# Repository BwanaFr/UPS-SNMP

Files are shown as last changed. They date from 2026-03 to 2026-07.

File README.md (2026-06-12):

# USB UPS to SNMP

## Introduction

This small device is attended to publish USB UPS (tested on some APC models) values to SNMP (v2c).

## Building

### Hardware
Hardware design files (PCB and 3D enclosure) is stored in the `hardware` folder.

### Firmware
The ESP32S3 firmware is built with PlatformIO.
Releases of the firmware are available on my GitHub page.

#### Configuration names
Some configurations are supported.

## Usage
Connect an USB cable in the USB A connector, a PoE enabled RJ45 ethernet connection.
The device is starting using a default IP of 10.10.11.200.
Please navigate to http://10.10.11.200 to change settings (your PC needs to be on the same network).

### Reset to default using buttons procedure
You can do a "on site" reset using the navigation button. To do so, please use this procedure.

1. Connect ethernet cable
2. You have one second to push the button
3. The LED will go white
4. Relase the button
5. Within 200ms, press again the buton
6. Device will start with default configuration

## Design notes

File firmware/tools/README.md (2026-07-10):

UPS-SNMP tools suite
---

# Description

Small Python scripts to performs "automated" actions on UPS-SNMP devices.
The main usage is to batch flash a new firmware version.

# Installation

Install a recent version of Python (>3.6)

Create a new Python venv
``` bash
> python -m venv /path/to/new/virtual/environment
```

Activate it:

Linux:
```bash
> source /path/to/new/virtual/environment/bin/activate
```

Windows (Powershell):
```powershell
> /path/to/new/virtual/environment\Scripts\Activate.ps1
```

Install dependencies (from this folder):
``` bash
> pip install -e .
```

# Usage
``` bash
> python -m ups-snmp-tools
usage: ups-snmp tool [-h] [--timeout TIMEOUT] [--ipColumn IPCOLUMN] [--nameColumn NAMECOLUMN]
                     [--nameSubstitution NAMESUBSTITUTION] [--sheetName SHEETNAME] [--fixName]
                     list update
```

Two parameters are mandatory:
- list: Specify the Excel file listing devices IP and (optional) name
- update: Specify the path to the firmware update file (.fw)

Other parameters:
- timeout: Specify the HTTP timeout (seconds) to give up, default is 5s
- ipColumn: Specify the column in the Excel file containing the device IP address (starting from 1, defaut 2)
- nameColumn: Specify the column in the Excel file containing the device name (starting from 1). This parameter is optional.
- nameSubstitution: Specify a substitution to apply to device name syntax is `SEARCH/REPLACE` where SEARCH is the searched sequence and REPLACE is the replaced sequence.
- sheetName: Name of the Excel sheet to find data in the file.
- fixName: If set, the application will update the device name according to provided name and substitution.

Example:
```bash
python -m ups-snmp-tools devices.xlsx --update waveshare_esp32_eth_ch1115_v0.0.5.fw --nameColumn 1 --nameSubstitution "sw-/ups-" --ipSubstitution "10.10.10/10.10.11" --nameFilter "(?!.*core.*)(sw-.*)"
```

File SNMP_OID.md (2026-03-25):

# OID documentation

The OID documentaion is available directly on the device by browsing http://<device_IP>/oid.html

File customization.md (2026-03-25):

# Device customization

You can apply some device customization to fit your needs / company.
All customizations are made in a `Customization.hpp` file.
If this file exists, the compiler will include it and use customized features. If not, the default behaviour will be used.

## Customizing logo

You can set a custom logo by defining `CUSTOM_LOGO`.
Three variables needs to be set to provide logo data:
```cpp
const int16_t custom_logo_height = 34;              //Logo height in pixels
const int16_t custom_logo_width = 90;               //Logo width in pixels
const unsigned char custom_logo [] PROGMEM = ...    //Byte array containing logo data
```
The logo byte array can be created using [image2cpp](https://javl.github.io/image2cpp/).

## Enabling and customizing auto-configuration

The device can be configured using the button and the OLED display.
To ease the configuration using this UI, the user can set an IP suffix (a digit from 0 to 255) and the device will configure all the required parameters.
This feature is implemented by defining `HAS_AUTOCONFIG` and implementing a `AutoConfig` class.
The `AutoConfig` class have only one static function `static void applyAutoconfig(uint8_t suffix)`.
This function will be called when the user validate the auto-configuration suffix setting.

Implementation of this function is left free.

## Adding OID aliases

If you want to add some aliases to SNMP OID, you can define them in the `Customization.hpp` file.
To do so, define a `OID_ALIAS` and fill a `static const char* oidAlias[][2]` array.
The first column contains the alias value, the second contains the aliased one.
This array should end with two `nullptr` values to detect the end of it.

Adding an alias will not add it in the SNMP get-next request, and will be invisible with `snmp-walk` tool.

## Example `Customization.hpp` file

Here is an example of how you can customize the device.

```cpp
#ifndef _CUSTOMIZATION_HPP__
#define _CUSTOMIZATION_HPP__

#include <Arduino.h>
#include <Configuration.hpp>

/**
 * This file is used for customization of the device such as logo, product name...
 */

//Sets CUSTOM_LOGO to enable custom logo
#define CUSTOM_LOGO 1

//Custom logo height and width
const int16_t custom_logo_height = 34;
const int16_t custom_logo_width = 90;
//Custom logo bitmap (same as default in this example)
const unsigned char custom_logo [] PROGMEM = {
	0x00, 0x00, 0x00, 0x00, 0x00, 0x00, 0x00, 0x00, 0x00, 0x00, 0x00, 0x00, 0x00, 0x00, 0x00, 0x00, 
	0x00, 0x00, 0x00, 0x00, 0x00, 0x00, 0x00, 0x00, 0x00, 0x00, 0x00, 0x00, 0x00, 0x00, 0x00, 0x00, 
	0x00, 0x00, 0x00, 0x00, 0x00, 0x00, 0x00, 0x00, 0x00, 0x00, 0x00, 0x00, 0x00, 0x00, 0x00, 0x00, 
	0x00, 0x00, 0x00, 0x00, 0x00, 0x00, 0x00, 0x00, 0x00, 0x00, 0x00, 0x00, 0x00, 0x00, 0x00, 0x00, 
	0x00, 0x00, 0x00, 0x00, 0x00, 0x00, 0x00, 0x00, 0x00, 0x00, 0x00, 0x00, 0x00, 0x00, 0x84, 0xf0, 
	0xf0, 0x00, 0x00, 0x00, 0x01, 0xe0, 0x07, 0x00, 0x00, 0x00, 0x84, 0x89, 0x88, 0x00, 0x00, 0x00, 
	0x01, 0xe0, 0x0f, 0x00, 0x00, 0x00, 0x84, 0x89, 0x00, 0x00, 0x00, 0x00, 0x07, 0xff, 0xff, 0xe0, 
	0x00, 0x00, 0x84, 0x88, 0xe0, 0x00, 0x00, 0x00, 0x07, 0xff, 0xff, 0xe0, 0x00, 0x00, 0x84, 0xf0, 
	0x38, 0x00, 0x00, 0x00, 0x00, 0x00, 0x00, 0x00, 0x00, 0x00, 0x84, 0x80, 0x08, 0x00, 0x00, 0x00, 
	0x07, 0xff, 0xff, 0xe0, 0x00, 0x00, 0x44, 0x81, 0x08, 0x00, 0x00, 0x00, 0x07, 0x3f, 0xff, 0xe0, 
	0x00, 0x00, 0x78, 0x80, 0xf0, 0x00, 0x00, 0x00, 0x07, 0x3f, 0xff, 0xe0, 0x00, 0x00, 0x00, 0x00, 
	0x00, 0x00, 0x00, 0x00, 0x04, 0x0f, 0xe0, 0x60, 0x00, 0x00, 0x00, 0x00, 0x00, 0x00, 0x00, 0x00, 
	0x06, 0x0f, 0xf0, 0x60, 0x00, 0x00, 0x00, 0x00, 0x00, 0x00, 0x00, 0x00, 0x07, 0x3f, 0xff, 0xe0, 
	0x00, 0x00, 0x00, 0x00, 0x00, 0x00, 0x00, 0x00, 0x07, 0xbf, 0xff, 0xe0, 0x00, 0x00, 0x00, 0x00, 
	0x00, 0x00, 0x00, 0x00, 0x07, 0xff, 0xff, 0xe0, 0x00, 0x00, 0x00, 0x00, 0x00, 0x00, 0x00, 0x00, 
	0x07, 0xff, 0xff, 0xe0, 0x00, 0x00, 0x00, 0x00, 0x00, 0x00, 0x00, 0x00, 0x07, 0xff, 0xff, 0xe0, 
	0xc2, 0x1e, 0x31, 0x3b, 0xf8, 0xf1, 0xe0, 0x00, 0x00, 0x00, 0x00, 0x00, 0xc6, 0x23, 0x29, 0x10, 
	0x41, 0x19, 0x10, 0x00, 0x00, 0x00, 0x00, 0x00, 0xa6, 0x41, 0x29, 0x10, 0x42, 0x09, 0x10, 0x00, 
	0x00, 0x00, 0x00, 0x00, 0xaa, 0x41, 0x25, 0x10, 0x42, 0x09, 0x10, 0x00, 0x00, 0x00, 0x00, 0x00, 
	0x9a, 0x41, 0x25, 0x10, 0x42, 0x09, 0xe0, 0x00, 0x00, 0x00, 0x00, 0x00, 0x92, 0x41, 0x23, 0x10, 
	0x42, 0x09, 0x20, 0x00, 0x00, 0x00, 0x00, 0x00, 0x82, 0x23, 0x23, 0x10, 0x41, 0x19, 0x10, 0x00, 
	0x00, 0x00, 0x00, 0x00, 0x82, 0x1e, 0x21, 0x38, 0x40, 0xf1, 0x08, 0x00, 0x00, 0x00, 0x00, 0x00, 
	0x00, 0x00, 0x00, 0x00, 0x00, 0x00, 0x00, 0x00, 0x00, 0x00, 0x00, 0x00, 0x00, 0x00, 0x00, 0x00, 
	0x00, 0x00, 0x00, 0x00, 0x00, 0x00, 0x00, 0x00, 0x00, 0x00, 0x00, 0x00, 0x00, 0x00, 0x00, 0x00, 
	0x00, 0x00, 0x00, 0x00, 0x00, 0x00, 0x00, 0x00, 0x00, 0x00, 0x00, 0x00, 0x00, 0x00, 0x00, 0x00, 
	0x00, 0x00, 0x00, 0x00, 0x00, 0x00, 0x00, 0x00
};

//Enable auto-config support
#define HAS_AUTOCONFIG 1
class AutoConfig {
public:
	static void applyAutoconfig(uint8_t suffix)
	{
        //Using suffix, build IP and set default settings
		const IPAddress addr(10, 10, 10, suffix);
		const IPAddress subnet(255, 255, 255, 0);
		const IPAddress gateway(10, 10, 10, 1);
		configuration.setIPConfiguration(false, addr, subnet, gateway);
		configuration.setPingTestConfiguration(true, gateway, 2000, 5000);
		configuration.setSNMPPublicCommunity("public");
		const IPAddress switchIP(10, 10, 10, suffix + 1);
		configuration.setSwitchIP(switchIP);
	}
};

//OID aliases for retro-compatibility
#define OID_ALIAS 1
											//OLD					//NEW
static const char* oidAlias[][2] = {{"1.3.6.1.2.1.33.1.2.5", "1.3.6.1.2.1.33.1.6.1"},		//AC present
							 {nullptr, nullptr}};

#endif //#ifndef _CUSTOMIZATION_HPP__
```

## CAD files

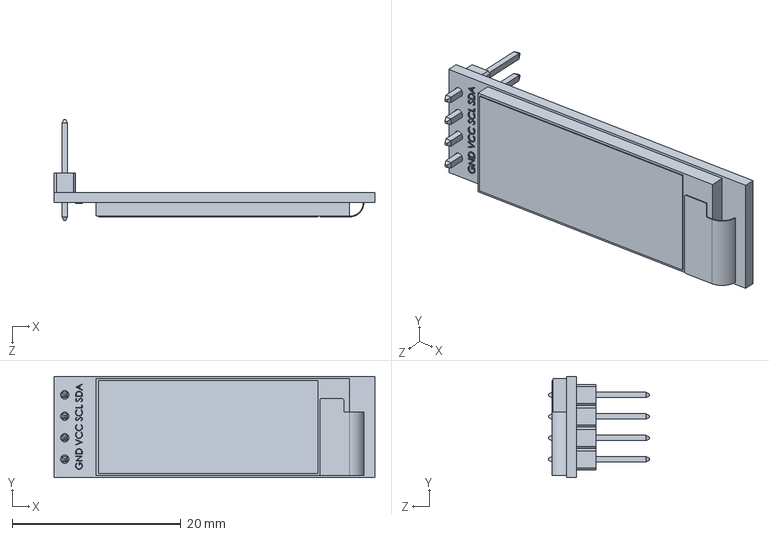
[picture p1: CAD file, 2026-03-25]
hardware/Enclosure/3D models/128x32-OLED.STEP
38.0 x 12.0 x 11.9 mm

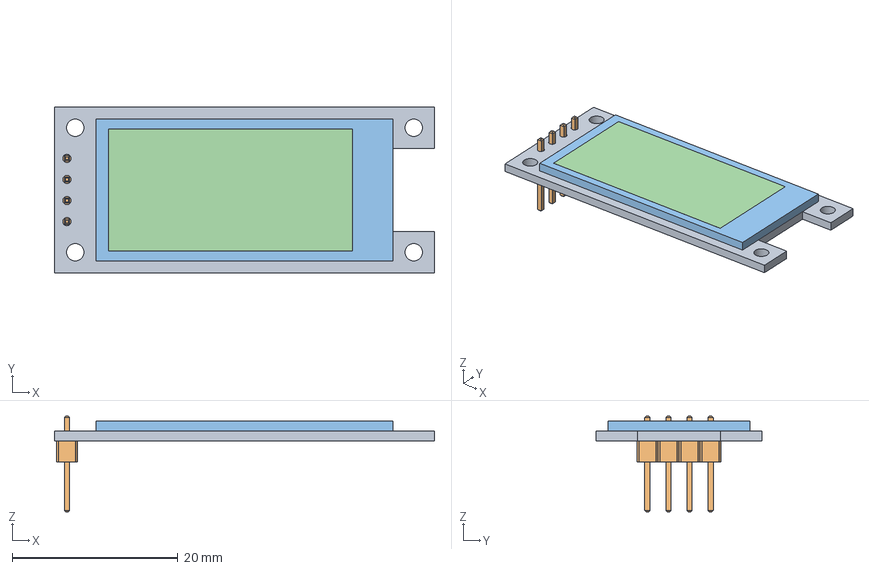
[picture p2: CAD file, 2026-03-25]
hardware/PCB/esp32-ups-snmp/3D/OLED_1.29_CH1115/OLED_1.29.FCStd
45.8 x 20.0 x 11.5 mm
Pcb_9bcc
J1_PinHeader_1x04_P254mm_Vertical_24511edf518d
Panel
AA

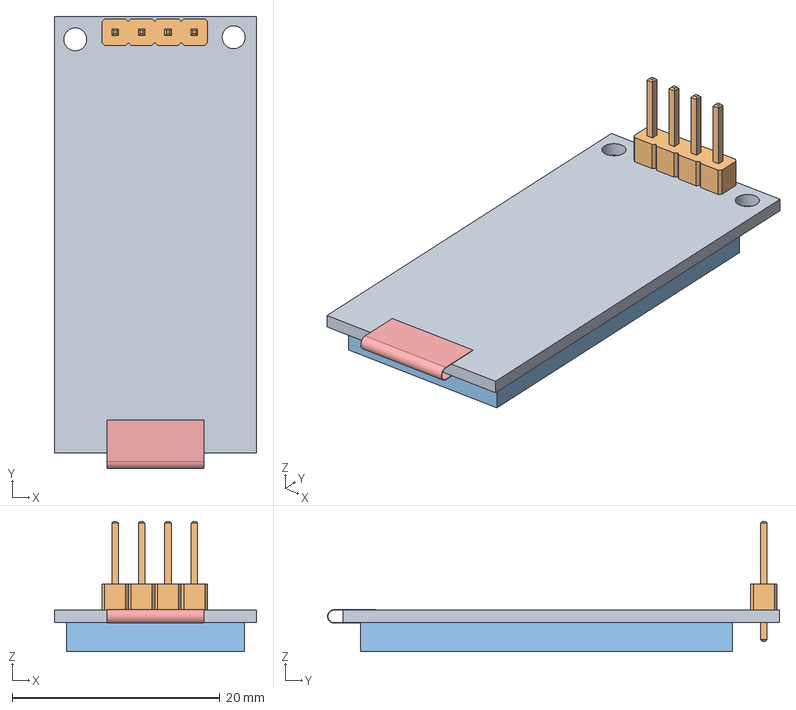
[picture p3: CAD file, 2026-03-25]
hardware/PCB/esp32-ups-snmp/3D/OLED_1.3/OLED_1_3/OLED_1_3.FCStd
19.4 x 43.5 x 12.5 mm
Pcb_5a1b
J1_PinHeader_1x04_P254mm_Vertical_41ee885aca97
ViewSurface
FlexPCB

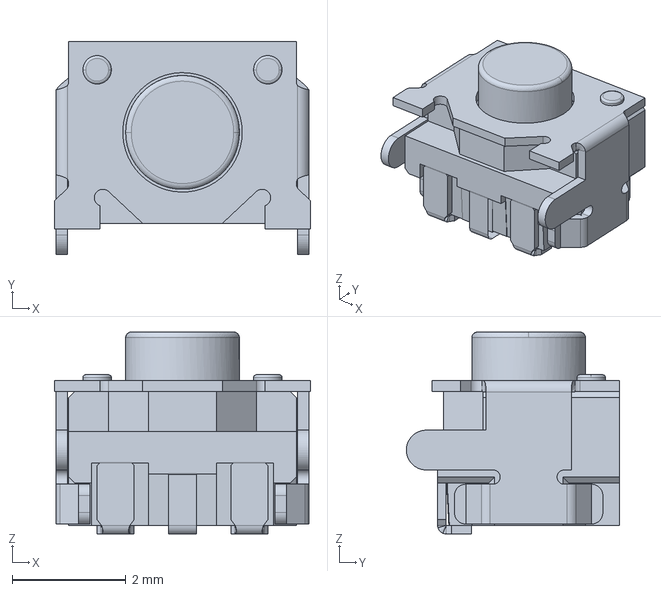
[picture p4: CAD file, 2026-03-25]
hardware/PCB/esp32-ups-snmp/3D/WaveshareETH/PTS845VM20PSMTR41M_LFS.stp
4.50 x 3.75 x 3.55 mm

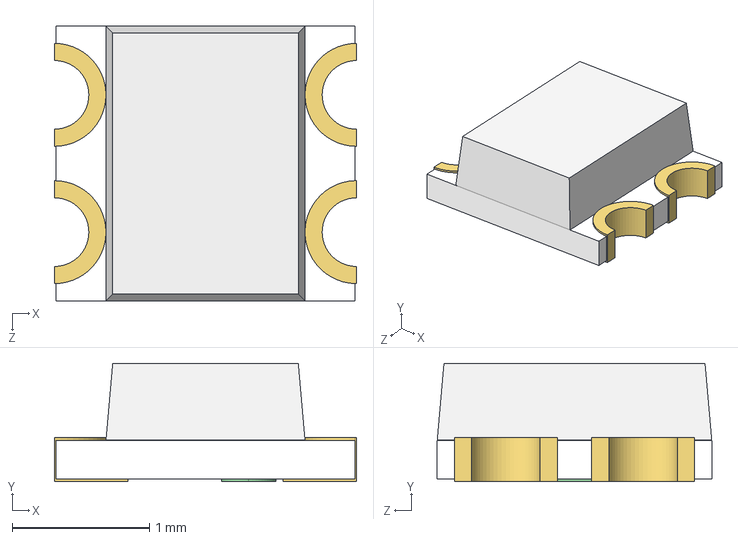
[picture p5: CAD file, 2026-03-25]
hardware/PCB/esp32-ups-snmp/3D/WS2812-2020.STEP
2.20 x 0.86 x 2.00 mm

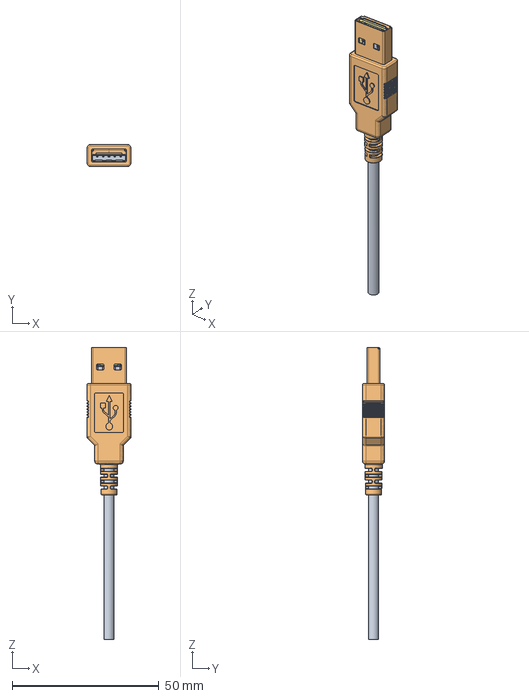
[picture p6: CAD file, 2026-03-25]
hardware/Enclosure/3D models/usb-a-plug.step
15.0 x 7.50 x 99.6 mm
USB_A_Plug001
USB_A_Plug

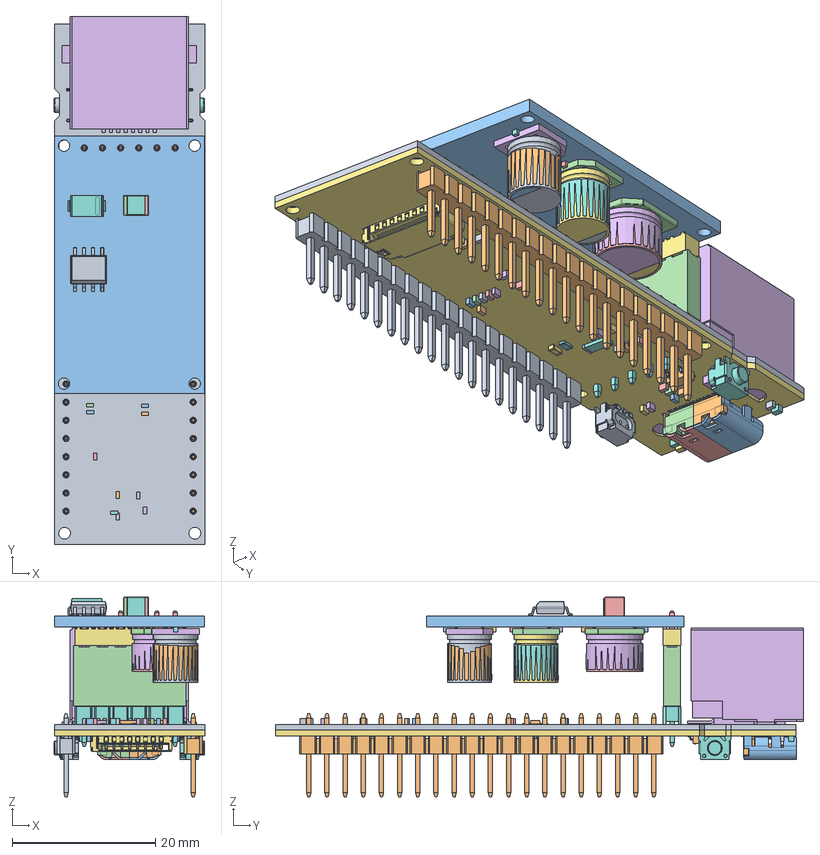
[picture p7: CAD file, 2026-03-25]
hardware/PCB/esp32-ups-snmp/3D/WaveShareETH.FCStd
21.1 x 73.8 x 28.0 mm
Extruded
Extruded001
Extruded002
Extruded003
Extruded004
Extruded005
Extruded006
Extruded007
Extruded008
Extruded009
Extruded010
Extruded011
Extruded012
CAPC1608(0603)
RESC1608(0603)
Extruded013
Extruded014
Extruded015
Extruded016
Extruded017
Extruded018
Extruded019
Extruded020
Extruded021
Extruded022
Extruded023
Extruded024
Extruded025
Extruded026
Extruded027
User_Library-Chip_Cap_MLCC_0201_(0603)
User_Library-Chip_Cap_MLCC_0201_(0603)001
User_Library-Chip_Cap_MLCC_0201_(0603)002
User_Library-Chip_Cap_MLCC_0201_(0603)003
User_Library-Chip_Cap_MLCC_0201_(0603)004
Extruded028
Extruded029
Extruded030
Extruded031
Extruded032
Extruded033
Extruded034
Extruded035
Extruded036
Extruded037
Extruded038
Extruded039
Extruded040
Extruded041
Extruded042
Extruded043
Extruded044
Extruded045
Extruded046
Extruded047
Extruded048
Extruded049
Extruded050
Extruded051
Extruded052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

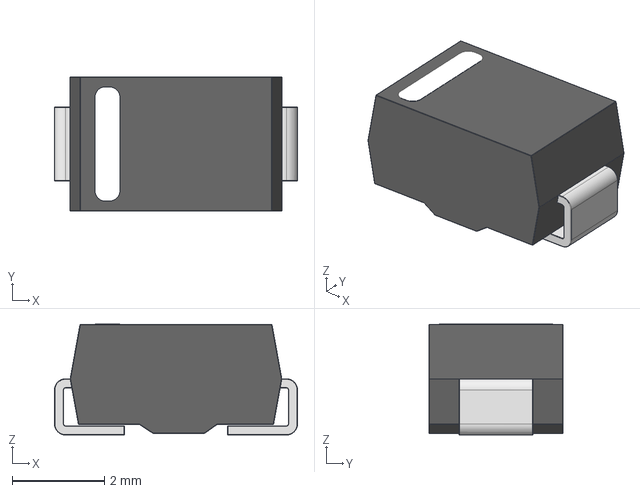
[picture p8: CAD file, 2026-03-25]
hardware/PCB/esp32-ups-snmp/3D/WaveshareETH/Diode SMA.igs
5.28 x 2.92 x 2.41 mm

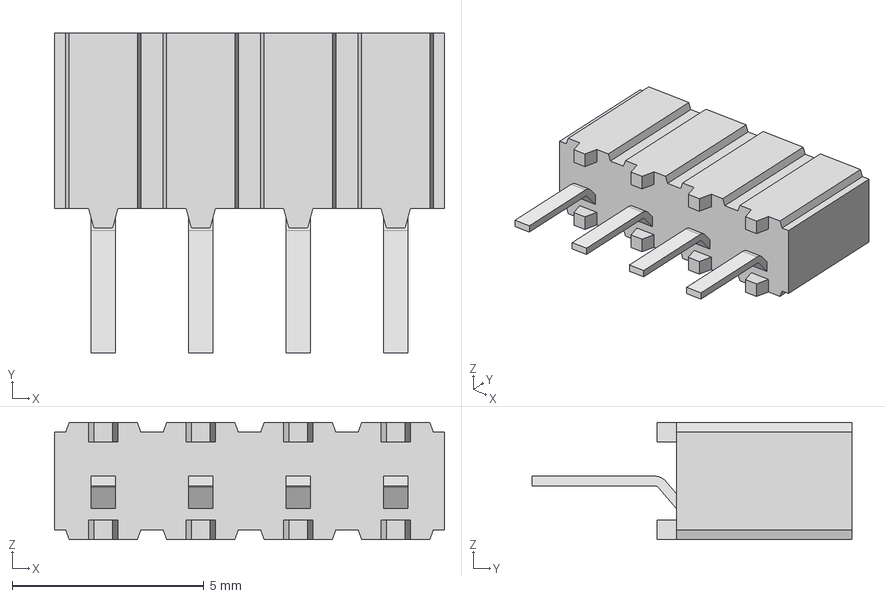
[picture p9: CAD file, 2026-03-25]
hardware/PCB/esp32-ups-snmp/3D/CES-104-01-T-S.stp
10.2 x 8.33 x 3.05 mm
CES-104-01-S_socket
010401TS
010401TS2

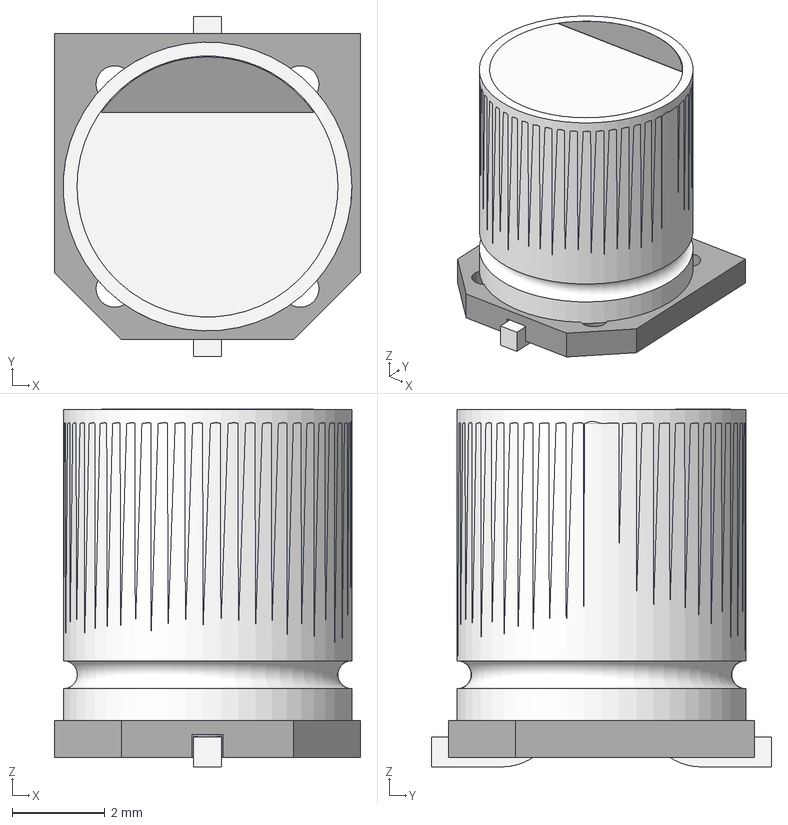
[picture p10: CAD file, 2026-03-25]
hardware/PCB/esp32-ups-snmp/3D/WaveshareETH/D6.3_H7.7.step
6.60 x 7.33 x 7.71 mm
Socle
Pins
Pins001
Mark

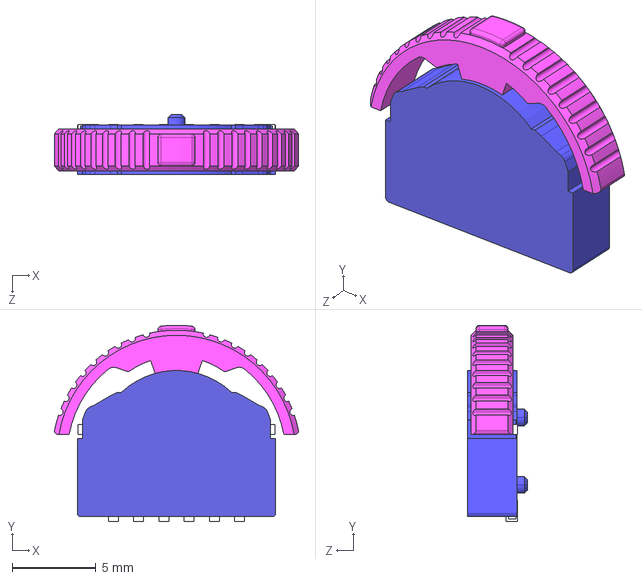
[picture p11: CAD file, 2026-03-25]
hardware/PCB/esp32-ups-snmp/3D/SLLB120300.STEP
14.5 x 11.7 x 3.60 mm

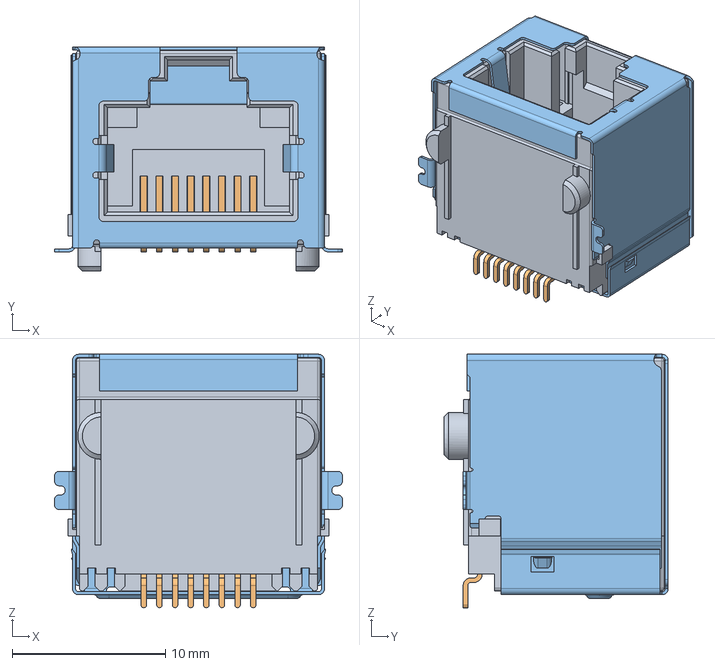
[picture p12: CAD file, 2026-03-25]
hardware/PCB/esp32-ups-snmp/3D/j6d018864l00112.stp
18.8 x 14.7 x 16.6 mm

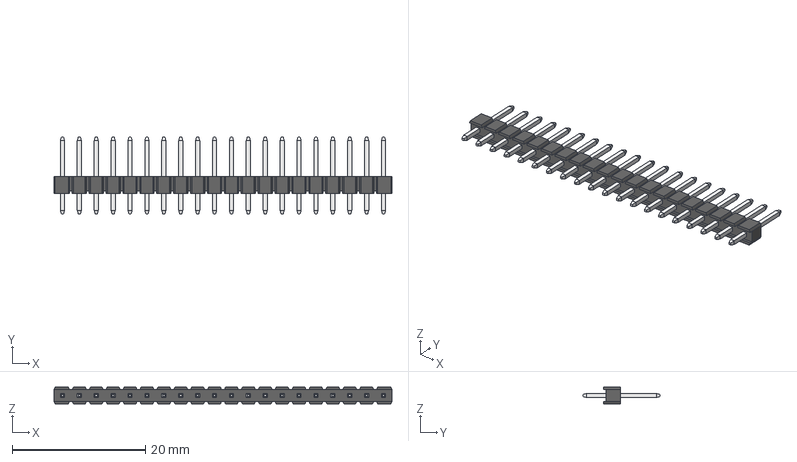
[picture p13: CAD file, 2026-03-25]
hardware/PCB/esp32-ups-snmp/3D/WaveshareETH/pcb_connector_890-18-020-10-001101.stp
50.8 x 11.6 x 2.54 mm

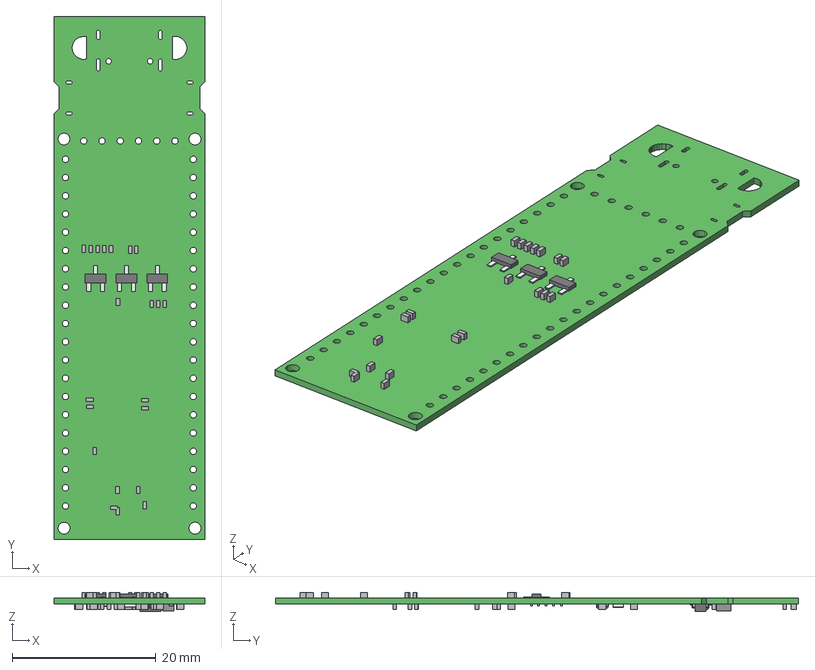
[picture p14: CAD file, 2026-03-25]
hardware/PCB/esp32-ups-snmp/3D/WaveshareETH/ESP32S3-ETH.step
21.0 x 72.8 x 2.71 mm
Extruded x 86
CAPC1608(0603)
RESC1608(0603)
User_Library-Chip_Cap_MLCC_0201_(0603) x 5

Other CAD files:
hardware/PCB/esp32-ups-snmp/3D/waveshare_esp32-s3_eth.step
hardware/PCB/esp32-ups-snmp/3D/Wurth_614004134726 (rev1).stp
hardware/PCB/esp32-ups-snmp/3D/S05B-ZESK-2D.STEP
hardware/PCB/esp32-ups-snmp/3D/WaveshareETH/SSQ-106-03-L-S.stp
hardware/Enclosure/3D models/USB A Plug.iges
hardware/PCB/esp32-ups-snmp/3D/WaveshareETH/1149882.stp
hardware/PCB/esp32-ups-snmp/3D/WaveshareETH/47571-0001.stp
hardware/PCB/esp32-ups-snmp/3D/WaveshareETH/70095740.stp
hardware/PCB/esp32-ups-snmp/3D/WaveshareETH/D8_H6.2_v2.step
hardware/PCB/esp32-ups-snmp/3D/WaveshareETH/ESQ-106-12-L-S.stp
hardware/PCB/esp32-ups-snmp/3D/WaveshareETH/SOIC08 narrow.igs
hardware/PCB/esp32-ups-snmp/3D/WaveshareETH/c1210c107m9pactu.stp
hardware/PCB/esp32-ups-snmp/3D/WaveshareETH/pcb_connector_890-80-006-10-001101.stp

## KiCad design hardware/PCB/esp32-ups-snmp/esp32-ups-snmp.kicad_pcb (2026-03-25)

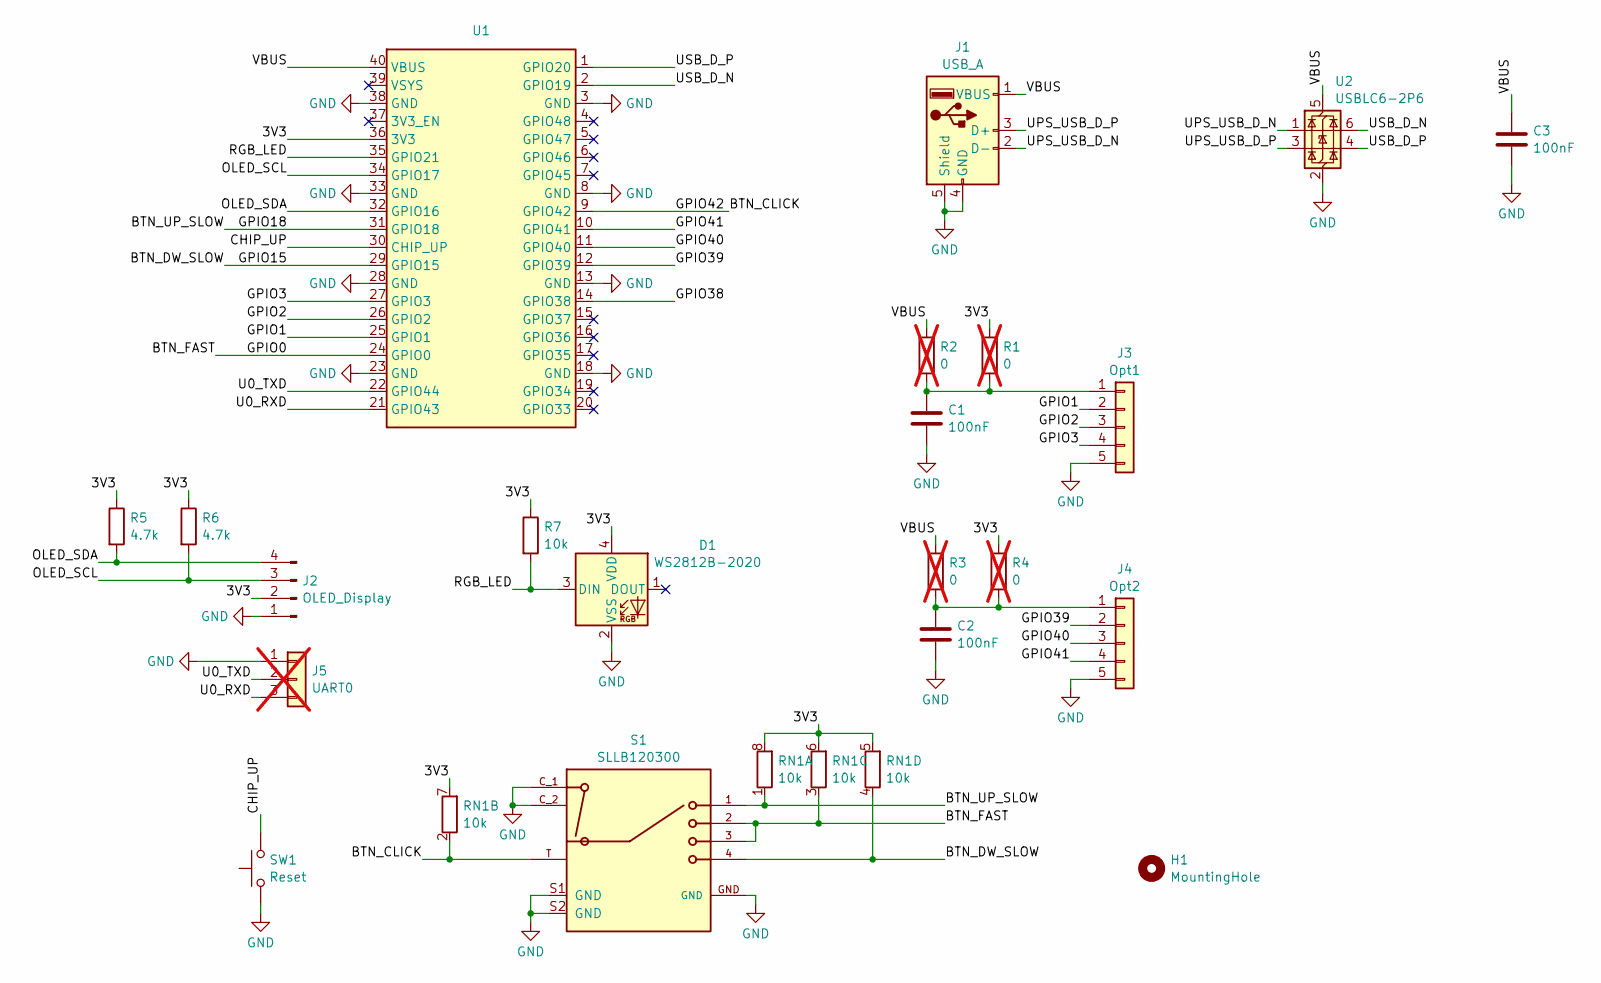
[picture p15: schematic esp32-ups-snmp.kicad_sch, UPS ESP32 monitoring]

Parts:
C1, C2, C3: 100nF; C_0603_1608Metric
D1: WS2812B-2020; LED_WS2812B-2020_PLCC4_2.0x2.0mm; LCSC C965555
H1: MountingHole; MountingHole_2.2mm_M2_DIN965
J1: USB_A; USB_A_Wuerth_614004134726_Horizontal
J2: OLED_Display; PinSocket_1x04_P2.54mm_Vertical
J3: Opt1; JST_ZE_S05B-ZESK-2D_1x05_P1.50mm_Horizontal
J4: Opt2; JST_ZE_S05B-ZESK-2D_1x05_P1.50mm_Horizontal
J5: UART0; PinHeader_1x03_P2.54mm_Vertical; not fitted
R1, R2, R3, R4: 0; R_0603_1608Metric; not fitted
R5, R6: 4.7k; R_0603_1608Metric
R7: 10k; R_0603_1608Metric
RN1: 10k; R_Array_Convex_4x0603; LCSC C29718
S1: SLLB120300; SW_SLLB120300; LCSC C255512
SW1: Reset; SW_SPST_B3U-3000P
U1: waveshare_esp32-s3_eth
U2: USBLC6-2P6; SOT-666

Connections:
/3V3: D1.4 (VDD), J2.2, R1.2, R4.2, R5.1, R6.1, R7.1, RN1.5 (R4.2), RN1.6 (R3.2), RN1.7 (R2.2), RN1.8 (R1.2), U1.36 (3V3)
/BTN_CLICK: RN1.2 (R2.1), S1.T, U1.9 (GPIO42)
/BTN_DW_SLOW: RN1.4 (R4.1), S1.4, U1.29 (GPIO15)
/BTN_FAST: RN1.3 (R3.1), S1.2, S1.3, U1.24 (GPIO0)
/BTN_UP_SLOW: RN1.1 (R1.1), S1.1, U1.31 (GPIO18)
/CHIP_UP: SW1.2, U1.30 (CHIP_UP)
/GPIO1: J3.2, U1.25 (GPIO1)
/GPIO2: J3.3, U1.26 (GPIO2)
/GPIO3: J3.4, U1.27 (GPIO3)
/GPIO38: U1.14 (GPIO38)
/GPIO39: J4.2, U1.12 (GPIO39)
/GPIO40: J4.3, U1.11 (GPIO40)
/GPIO41: J4.4, U1.10 (GPIO41)
/OLED_SCL: J2.3, R6.2, U1.34 (GPIO17)
/OLED_SDA: J2.4, R5.2, U1.32 (GPIO16)
/RGB_LED: D1.3 (DIN), R7.2, U1.35 (GPIO21)
/U0_RXD: J5.3, U1.21 (GPIO43)
/U0_TXD: J5.2, U1.22 (GPIO44)
/UPS_USB_D_N: J1.2 (D-), U2.1 (I/O1)
/UPS_USB_D_P: J1.3 (D+), U2.3 (I/O2)
/USB_D_N: U1.2 (GPIO19), U2.6 (I/O1)
/USB_D_P: U1.1 (GPIO20), U2.4 (I/O2)
/VBUS: C3.1, J1.1 (VBUS), R2.2, R3.2, U1.40 (VBUS), U2.5 (VBUS)
GND: C1.2, C2.2, C3.2, D1.2 (VSS), J1.4 (GND), J1.5 (Shield), J2.1, J3.5, J4.5, J5.1, S1.C_1, S1.C_2, S1.GND, S1.S1 (GND), S1.S2 (GND), SW1.1, U1.3 (GND), U1.8 (GND), U1.13 (GND), U1.18 (GND), U1.23 (GND), U1.28 (GND), U1.33 (GND), U1.38 (GND), U2.2 (GND)
unnamed: C1.1, J3.1, R1.1, R2.1
unnamed: C2.1, J4.1, R3.1, R4.1

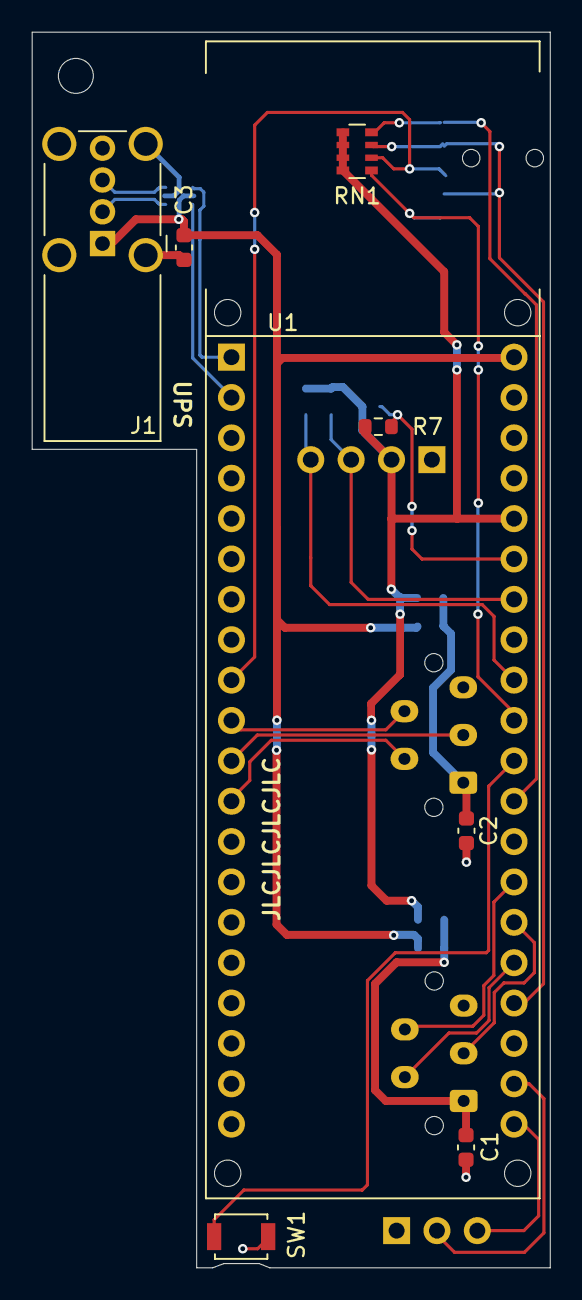
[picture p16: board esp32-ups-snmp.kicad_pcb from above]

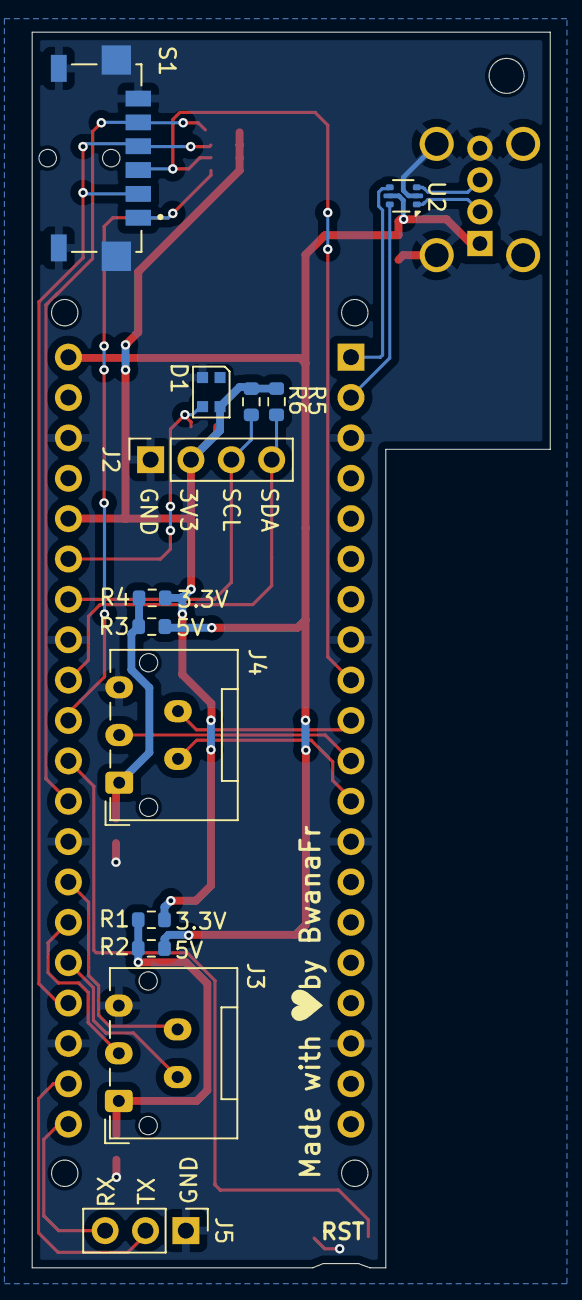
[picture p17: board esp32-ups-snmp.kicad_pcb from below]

Board: 2 copper layers, 32.6 x 77.8 mm, 22 parts (13 on the bottom side), 25 nets.

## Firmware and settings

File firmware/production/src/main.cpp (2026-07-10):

#include <Arduino.h>

#include <ETH.h>
#include <SPI.h>
#include <Webserver.hpp>
#include <WiFi.h>
#include <stdint.h>
#include <stdio.h>
#include <inttypes.h>

#include "CiscoSwitchInfo.hpp"
#include "UPSSNMPAgent.hpp"
#include "UPSHIDDevice.hpp"
#include "Configuration.hpp"
#include "UI.hpp"
#include "GlobalStatus.hpp"
#include "NetworkStatus.hpp"
#include "NavButton.hpp"

#ifdef HAS_TEMP_PROBE
#include "Temperature.hpp"
#endif

#include "DevicePins.hpp"

#include "Pinger.hpp"
#include "esp_log.h"


UPSSNMPAgent snmpAgent;


static const char* TAG = "Main";

/**
 * Configuration changed
 */
void configChanged(DeviceConfiguration::Parameter what)
{
    switch(what){
        case DeviceConfiguration::Parameter::DEVICE_NAME:
        {
            std::string deviceName;
            configuration.getDeviceName(deviceName);
            ETH.setHostname(deviceName.c_str());
            break;
        }
        case DeviceConfiguration::Parameter::IP_CONFIGURATION:
        {
            IPAddress ip, subnet, gateway;
            bool useDHCP;
            configuration.getIPConfiguration(useDHCP, ip, subnet, gateway);
            //Configure ETH
            if(useDHCP){
                ESP_LOGI(TAG, "New IP config : Use DHCP");
                ETH.config();
            }else{
                ESP_LOGI(TAG, "New IP config :");
                ESP_LOGI(TAG, "IP: %s", ip.toString().c_str());
                ESP_LOGI(TAG, "Subnet: %s", subnet.toString().c_str());
                ESP_LOGI(TAG, "Gateway: %s", gateway.toString().c_str());
                ETH.config(ip, gateway, subnet);
            }
            break;
        }
        case DeviceConfiguration::Parameter::PING_TEST_CONFIGURATION:
        {
            bool useGateway = false;
            IPAddress ip = INADDR_NONE;
            int interval = 0;
            int timeout = 0;
            configuration.getPingTestConfiguration(useGateway, ip, interval, timeout);
            // ESP_LOGI(TAG, "New ping config : GW? %d, IP:%s, Interval: %d, Timeout: %d", useGateway, ip.toString().c_str(), interval, timeout);
            pinger.configure(useGateway, ip, interval, timeout);
            break;
        }
        case DeviceConfiguration::Parameter::SNMP_COMMUNITY:
        {
            std::string snmpComStr;
            configuration.getSNMPPublicCommunity(snmpComStr);
            snmpAgent.setSNMPCommunity(snmpComStr);
            ciscoFetcher.setSNMPCommunity(snmpComStr);
            break;
        }
        case DeviceConfiguration::Parameter::SWITCH_IP:
        {
            IPAddress ip;
            configuration.getSwitchIP(ip);
            ciscoFetcher.setSwitchIPAddress(ip);
            break;
        }
    }
}

void WiFiEvent(arduino_event_id_t event)
{
    networkStatus.networkEvent(event);
    switch (event) {
    case ARDUINO_EVENT_ETH_START:
    {
        std::string deviceName;
        configuration.getDeviceName(deviceName);
        ETH.setHostname(deviceName.c_str());
    }
        break;
    case ARDUINO_EVENT_ETH_CONNECTED:
        ESP_LOGI(TAG, "ETH Connected");
        break;
    case ARDUINO_EVENT_ETH_GOT_IP:
        ESP_LOGI(TAG, "ETH MAC: %s, IPv4: %s, Duplex: %s, %uMbps", ETH.macAddress().c_str(), ETH.localIP().toString().c_str(),
                    ETH.fullDuplex() ? "FULL" : "HALF", ETH.linkSpeed());
        //Ethernet available starts network services
        webServer.start();
        snmpAgent.start();
        pinger.start();
        ciscoFetcher.start();
        ui.gotIP();
        break;
    case ARDUINO_EVENT_ETH_DISCONNECTED:
        ESP_LOGI(TAG, "ETH Disconnected, Stop services");
        webServer.stop();
        snmpAgent.stop();
        pinger.stop();
        ciscoFetcher.stop();
        break;
    case ARDUINO_EVENT_ETH_STOP:
        ESP_LOGI(TAG, "ETH Stopped");
        break;
    default:
        break;
    }
}

void setup()
{
    //Removes logging from ESP32PingMs lib
    esp_log_level_set("ping", ESP_LOG_ERROR);

    //Starts serial
    Serial.begin(115200);

    //Stops ESP if last reset is panic
    // esp_reset_reason_t reason = esp_reset_reason();
    // if(reason == ESP_RST_PANIC){
    //     while(true){
    //         delay(1);
    //     }
    // }

    //Initializes configuration
    configuration.begin();

    //Register a listener to know configuration changes
    configuration.registerListener(configChanged);

#ifdef HAS_TEMP_PROBE
    //Starts temperature readout
    tempProbe.begin();
#endif
    //Starts user interraction
    ui.begin();

    //Starts Ethernet
    WiFi.onEvent(WiFiEvent);
    ESP_LOGI(TAG, "Starting ethernet");
    if (!ETH.begin(ETH_PHY_W5500, 1, ETH_CS_PIN, ETH_INT_PIN, ETH_RST_PIN,
                    SPI3_HOST,
                    ETH_SCLK_PIN, ETH_MISO_PIN, ETH_MOSI_PIN, 60 /* SPI clock speed MHz*/)) {
        ESP_LOGE(TAG, "Ethernet start Failed!");
        UserLed::getInstance()->fatal();
    }

    //Loads configuration from flash (Default used if flash empty)
    //Loading the configuration will NOT send a IP configuration change event
    configuration.load();

    //Starts SNMP agent
    snmpAgent.begin();

    //Configure HID bridge
    upsDevice.begin();

    //Setup the web server
    webServer.setup();

    //Global device status reading
    globalStatus.begin();

    //Reconfigure IP after starting all services
    configChanged(DeviceConfiguration::Parameter::IP_CONFIGURATION);
}

void loop()
{
    //Don't need this Arduino shit
    vTaskDelete(NULL);
}

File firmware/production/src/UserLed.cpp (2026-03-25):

/*
**    This software license is not yet defined.
**
*/
#ifdef RGB_LED_PIN
#include "UserLed.hpp"

UserLed* UserLed::instance_ = nullptr;

UserLed::UserLed() : state_(State::INITIALIZING),
            ledStrip_(RGB_LED_PIN, 1),
            ledColor_(GRBPixel{0,0,0}),
            customColor_(GRBPixel{0,0,0}),
            isOn_(false), isDim_(false), waitTicks_(portMAX_DELAY),
            semaphore_(xSemaphoreCreateMutex()),
            newStateQueue_(xQueueCreate(10, sizeof(NewState)))
{
    instance_ = this;
    StatusProvider::registerAlarmListener(this);
}

UserLed::~UserLed()
{
    if(semaphore_){
        vSemaphoreDelete(semaphore_);
        semaphore_ = nullptr;
    }
}

void UserLed::begin(){
    ledStrip_.begin();
    xTaskCreatePinnedToCore(
        ledTask,
        "ledTask",
        2048,
        (void*)this,
        tskIDLE_PRIORITY + 1, NULL,
        ESP_TASK_MAIN_CORE ? 0 : 1
    );
}

void UserLed::ledTask(void* param)
{
    UserLed* tsk = static_cast<UserLed*>(param);
    while(true){
        tsk->loop();
    }
}

void UserLed::loop(){
    NewState newState;
    if(xQueueReceive( newStateQueue_, &newState, waitTicks_) == pdPASS ){
        if(newState.state == State::DIM){
            if(!isDim_){
                ledStrip_.setScale(DIM_SCALE);
                ledStrip_.setLed(0, ledColor_);
                isDim_ = true;
                return;
            }
        }else if(newState.state == State::UNDIM){
            if(isDim_){
                ledStrip_.setScale(100.0);
                ledStrip_.setLed(0, ledColor_);
                isDim_ = false;
                return;
            }
        }else if(newState.state == State::CUSTOM){
            ledColor_ = newState.payload;
            ledStrip_.setLed(0, ledColor_);
            waitTicks_ = portMAX_DELAY;
        }else{
            isOn_ = false;
            waitTicks_ = pdMS_TO_TICKS(STATE_SETTINGS[static_cast<int32_t>(newState.state)].timeOn);
        }
        xSemaphoreTake(semaphore_, portMAX_DELAY);
        state_ = newState.state;
        xSemaphoreGive(semaphore_);
    }
    if(state_ != State::CUSTOM){
        isOn_ = !isOn_;
        waitTicks_ = pdMS_TO_TICKS(isOn_ ? STATE_SETTINGS[static_cast<int32_t>(state_)].timeOn : STATE_SETTINGS[static_cast<int32_t>(state_)].timeOff);
        ledColor_ = static_cast<uint32_t>(isOn_ ? STATE_SETTINGS[static_cast<int32_t>(state_)].onColor : STATE_SETTINGS[static_cast<int32_t>(state_)].offColor);
        ledStrip_.setLed(0, ledColor_);
    }
}

void UserLed::fatal()
{
    //Don't send if already in fatal
    setNewState(State::FATAL);
}

void UserLed::endInitialization()
{
    AlarmSeverity alarmSev = StatusProvider::getMostAlarmSeverity();
    switch(alarmSev){
        case AlarmSeverity::INACTIVE:
            setNewState(State::OK);
            break;
        case AlarmSeverity::WARNING:
            setNewState(State::WARNING);
            break;
        case AlarmSeverity::ERROR:
            setNewState(State::ERROR);
            break;
    }
}

void UserLed::setNewState(State newState, uint32_t payload)
{
    if((newState == State::CUSTOM) || (newState != state_)){
        NewState state = {newState, payload};
        xQueueSend( /* The handle of the queue. */
                newStateQueue_,
                ( void * ) &state,
                ( TickType_t ) 0 );
    }
}

UserLed::State UserLed::getState()
{
    State ret;
    xSemaphoreTake(semaphore_, portMAX_DELAY);
    ret = state_;
    xSemaphoreGive(semaphore_);
    return ret;
}

void UserLed::customColor(uint8_t r, uint8_t g, uint8_t b)
{
    uint32_t customColor = (r<<16) | (g<<8) | b;
    setNewState(State::CUSTOM, (uint32_t)customColor);
}

void UserLed::customHSV(float hue, float saturation, float value)
{
    uint8_t r,g,b;
    HSVToRGB(hue, saturation, value, r, g, b);
    customColor(r, g, b);
}

void UserLed::HSVToRGB(float hue, float saturation, float value, uint8_t& red, uint8_t& green, uint8_t& blue)
{
    float r = 0, g = 0, b = 0;
	if (saturation == 0)
	{
		r = value;
		g = value;
		b = value;
	}
	else
	{
		int i;
		double f, p, q, t;

		if (hue == 360)
			hue = 0;
		else
			hue = hue / 60;

		i = (int)trunc(hue);
		f = hue - i;

		p = value * (1.0 - saturation);
		q = value * (1.0 - (saturation * f));
		t = value * (1.0 - (saturation * (1.0 - f)));

		switch (i)
		{
		case 0:
			r = value;
			g = t;
			b = p;
			break;

		case 1:
			r = q;
			g = value;
			b = p;
			break;

		case 2:
			r = p;
			g = value;
			b = t;
			break;

		case 3:
			r = p;
			g = q;
			b = value;
			break;

		case 4:
			r = t;
			g = p;
			b = value;
			break;

		default:
			r = value;
			g = p;
			b = q;
			break;
		}
	}

	red = (uint8_t)(r * 255);
	green = (uint8_t)(g * 255);
	blue = (uint8_t)(b * 255);
}

void UserLed::alarmChanged(const AlarmInfo& info)
{
    if((state_ == State::OK)  || (state_ == State::ERROR) || (state_ == State::WARNING)){
        //Not fatal or initalizing, we can use alarms delivered by StatusProviders
        AlarmSeverity severity = info.severity;
        if(severity == AlarmSeverity::ERROR){
            setNewState(State::ERROR);
        }else if(severity == AlarmSeverity::WARNING){
            setNewState(State::WARNING);
        }else if(severity == AlarmSeverity::INACTIVE){
            endInitialization();
        }
    }
}

void UserLed::setResetSequence(int seqNum)
{
    switch(seqNum){
        case 1:
            setNewState(State::INIT_RESET_1);
            break;
        case 2:
            setNewState(State::INIT_RESET_2);
            break;
        case 3:
            setNewState(State::INIT_RESET_3);
            break;
    }
}

void UserLed::dim(bool dim)
{
    if(dim != isDim_){
        setNewState(dim ? State::DIM : State::UNDIM);
    }
}

#endif

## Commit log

2026-03-25 First public commit
    [1149882.stp, 128x32-OLED.STEP, 47571-0001.stp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]
2026-03-25 Added small firmware to test hardware boards
2026-06-24 Refresh switch interfaces every 30s if not interfaces found
2026-06-24 Added switch status in webpage
2026-06-24 Added CPU temperature on webpage
2026-06-29 Fixed init when empty flash
    [main.cpp]

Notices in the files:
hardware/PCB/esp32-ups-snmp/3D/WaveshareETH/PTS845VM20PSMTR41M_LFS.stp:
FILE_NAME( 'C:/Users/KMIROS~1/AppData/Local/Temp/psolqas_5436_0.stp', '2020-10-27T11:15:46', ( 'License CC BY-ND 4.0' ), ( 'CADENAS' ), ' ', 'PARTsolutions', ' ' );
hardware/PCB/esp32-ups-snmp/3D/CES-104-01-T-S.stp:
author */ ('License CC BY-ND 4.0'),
